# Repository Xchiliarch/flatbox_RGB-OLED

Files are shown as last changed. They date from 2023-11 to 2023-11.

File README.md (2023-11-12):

# Flatbox_RGB-OLED—A remix of Flatbox_rev5

- [What's this?](#whats-this)
- [What's new?](#whats-new)
- [What you need?](#what-you-need)

## What's this?

An adaption from [flatbox rev_5](https://github.com/Xchiliarch/flatbox_RGB-OLED/tree/master/hardware-rev5) , added RGB, OLED support and a new button.

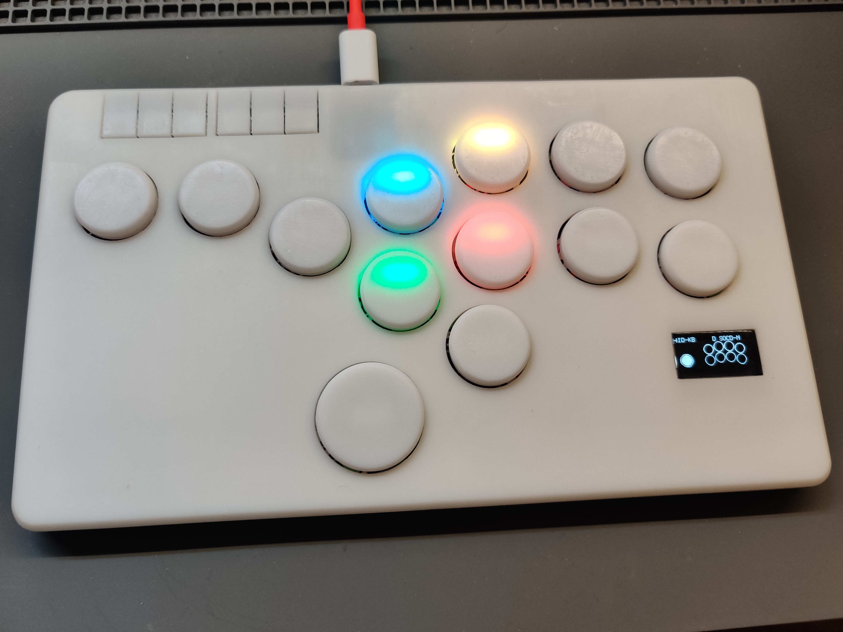
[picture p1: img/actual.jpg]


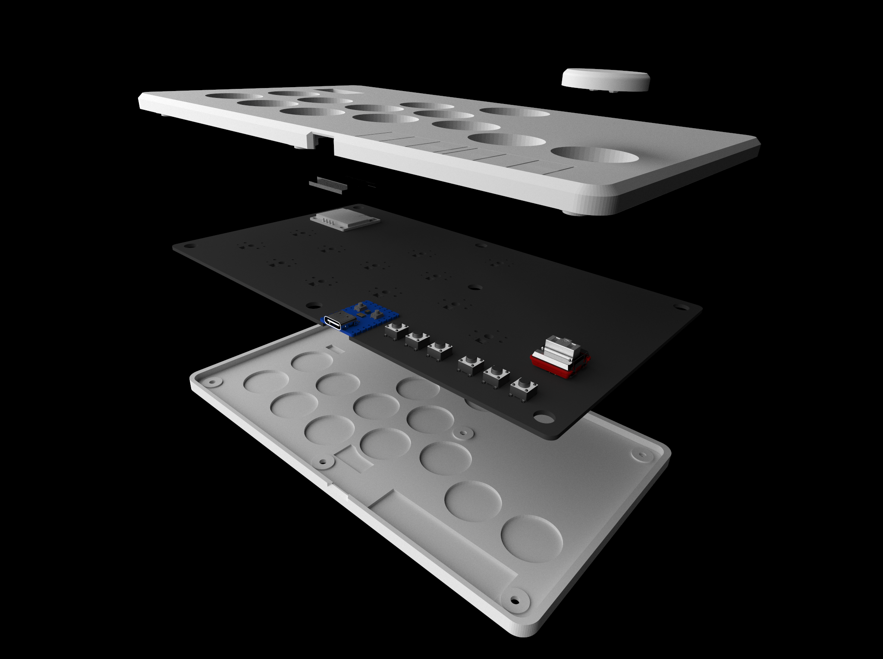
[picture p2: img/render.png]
render


## What's new?
- added RGB&OLED support
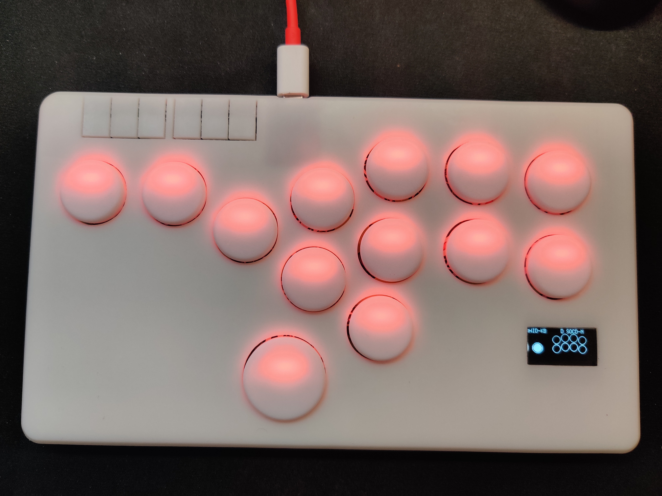
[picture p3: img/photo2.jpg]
actual2

- a new button

- buttons are at same level with the case when pressed down

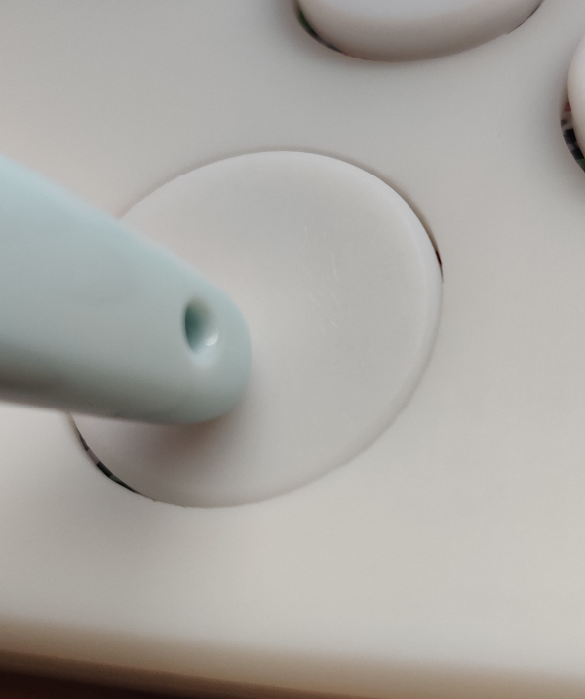
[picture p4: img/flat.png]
flat
  

## What you need?

| Parts | Name | Pcs  | Price |
| :---: | :--: | :---: | :---: |
|  | Waveshare RP2040-ZERO |  1 | ￥19 |
| choc | Kailh Choc V1 Switch | 13 | ￥3.2 ×13 |
| led | WS2812B 3528LED | 13 | ￥0.4 ×13 |
| insert | M3×5×4.2 Heat Set Insert | 7 | ￥0.09×7 |
| screw | M3×6 Flat-head Screw |  7 | ￥0.02×7  |
| OLED | SSD1306 0.96" OLED Display |  1 | ￥8 |
| c | 005 100NF capacitor | 13 | ￥0.03×13 |
| tact | 6mm×6mm×5mm tact switch | 6 | ￥0.12×6 |
| PCB | PCB | 1 | ￥110 for 5Pcs |
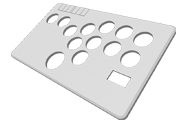
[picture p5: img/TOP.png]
TOP
|  | TOP case | 1 | ￥45* |
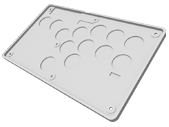
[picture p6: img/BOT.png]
BOT
|  | BOT case | 1 | ￥34* |
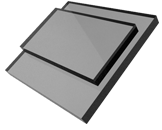
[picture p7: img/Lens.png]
LENS
|  | LENS(Transparent) | 1 | ￥12** |
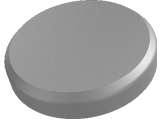
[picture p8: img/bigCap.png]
|  | big Cap | 1 | ￥2 |
| Bigcap | Small cap | 12 | ￥2×12 |

### Additional Info

All 3D printed case are from  JLC's 3D printing service (Sanweihou) and PCB order from JLC.

*: using  9000R, will be cheaper with X Resin.

**: using 8001+ Surface Finish: Oil Spraying. will be cheaper to sand it yourself.

## Credits

This project is made possible with the help of [GP2040-CE](https://github.com/OpenStickCommunity/GP2040-CE) by OpenStickCommunity and [Flatbox](https://github.com/jfedor2/flatbox) by jfedor2.

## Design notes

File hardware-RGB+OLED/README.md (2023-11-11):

## How to build

To make one you will need:

- 3D printed case TOP, BOT and LENS(transparent)
- PCB **thickness 1.6mm**
- 1x Waveshare RP2040-Zero
- 13x Kailh low profile (**choc v1**) switches
- 3D printed buttoncaps : **12x ButtoncapSmall** and **1x ButtoncapBig**
- 7x Heat-Set Inserts M3x5x4.2
- 7x M3x6 flat-end screws
- 6x 6x6x5  tact switches
- 13x WS2812B LED(3528)
- 13x 0805 100NF capacitor
- 1x SSD106 0.96" OLED Display (PIN SEQUENCE **MUST BE GND VSS SCL SDA**)

### NOTICE

- The three control buttons on the right (Fn,R3,L3)needed to be soldered with fly wires onto the back of the RP2040-ZERO. You can ignore the three buttons and still work well with only HOME SELECT and START, but it is better to solder the buttons on to the PCB in order to protect the vulnerable buttoncap on the top case.

- You need to cut off OLED pins that stretch out after being soldered on to the PCB to make it fit into the case. You may want to sand the pins as well.

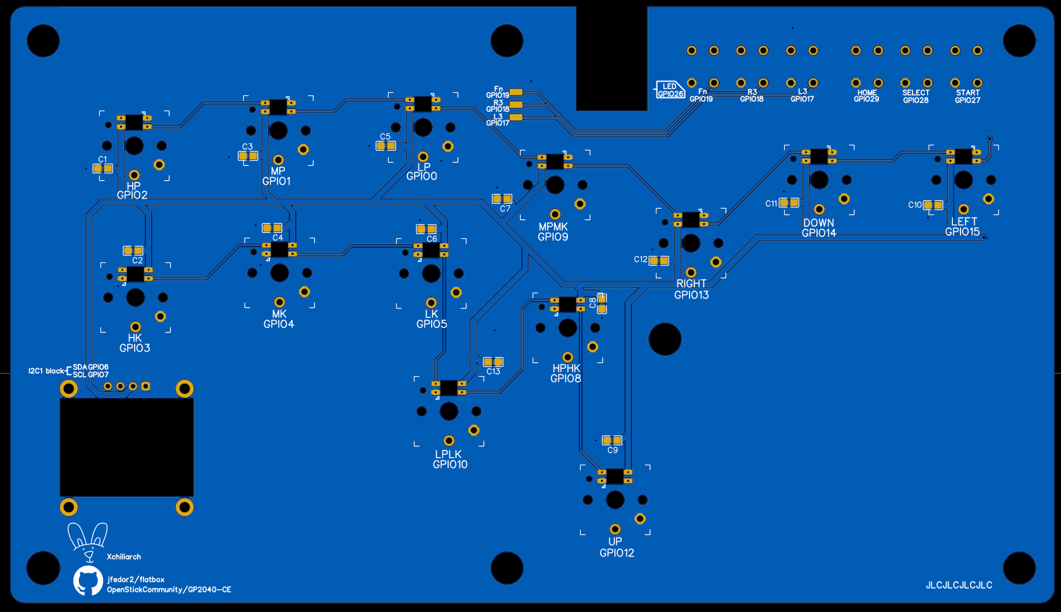
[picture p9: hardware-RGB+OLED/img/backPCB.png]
backPCB
 

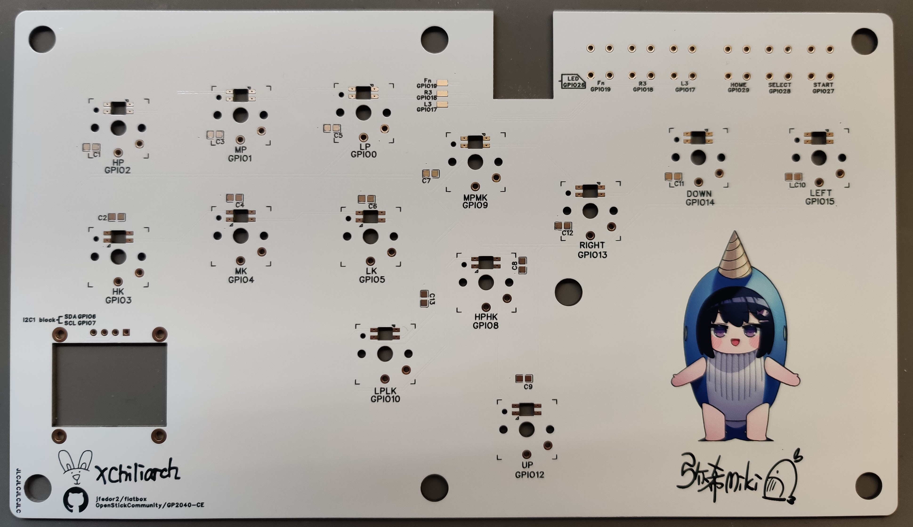
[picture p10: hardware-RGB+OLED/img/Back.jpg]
Back


PCB design licensed under [CC BY-SA 4.0](https://creativecommons.org/licenses/by-sa/4.0/).

PCB designed with JLC EDA.

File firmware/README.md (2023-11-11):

## How to use

- flash flash_nuke.uf2 to device to ensure a clean environment for installation
- flash GP2040-CE_0.7.5_WaveshareZero.uf2 and wait for auto disconnect and reconnection
- disconnect the device and hold the second last button on the upper row and connect to computer

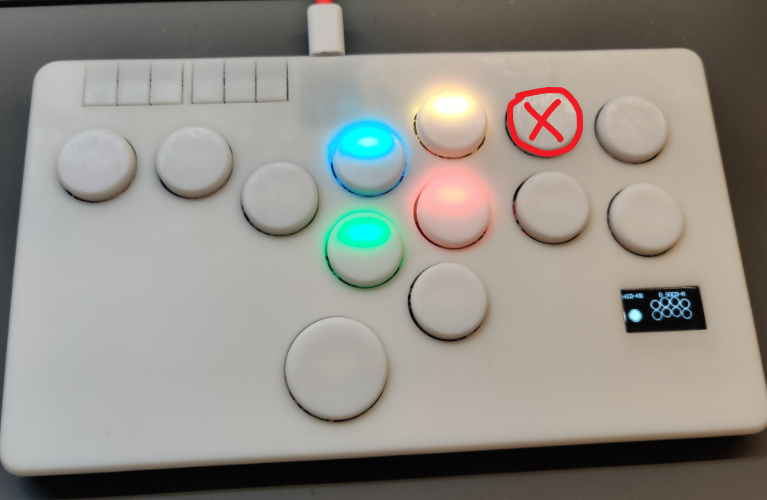
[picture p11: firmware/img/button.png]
button


- go to Data Backup and Restoration menu and load config.gp2040

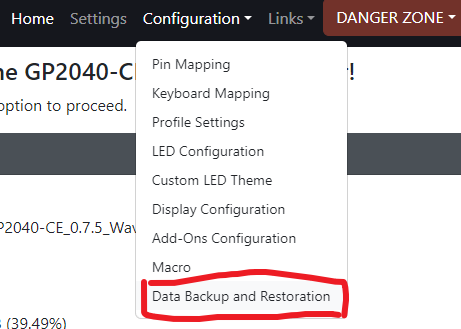
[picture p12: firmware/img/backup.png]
backup
  

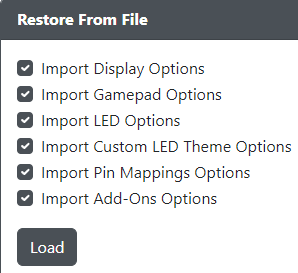
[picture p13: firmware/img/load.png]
load
  

- done!

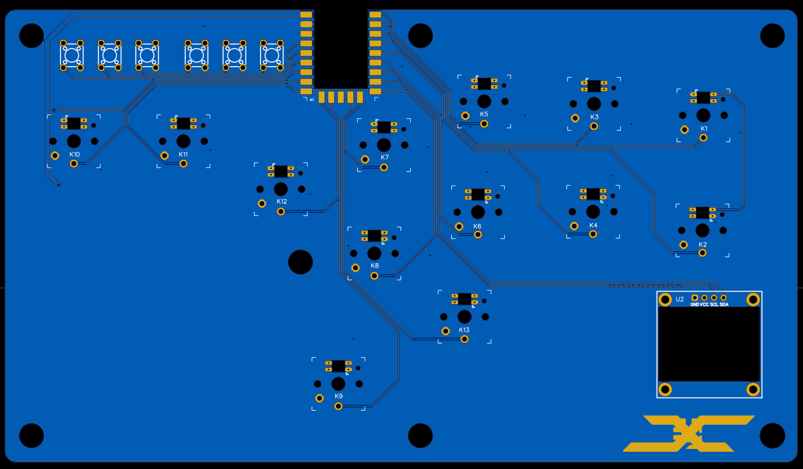
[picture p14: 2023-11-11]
hardware-RGB+OLED/img/frontPCB.png

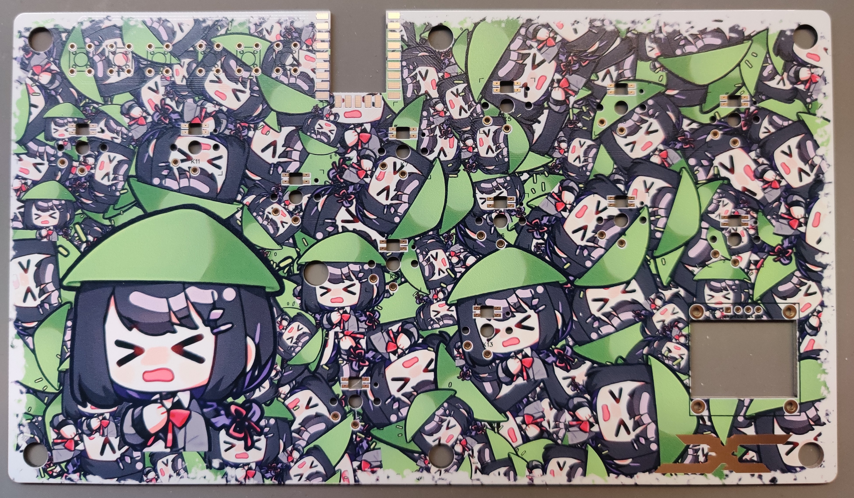
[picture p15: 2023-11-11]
hardware-RGB+OLED/img/Front.jpg

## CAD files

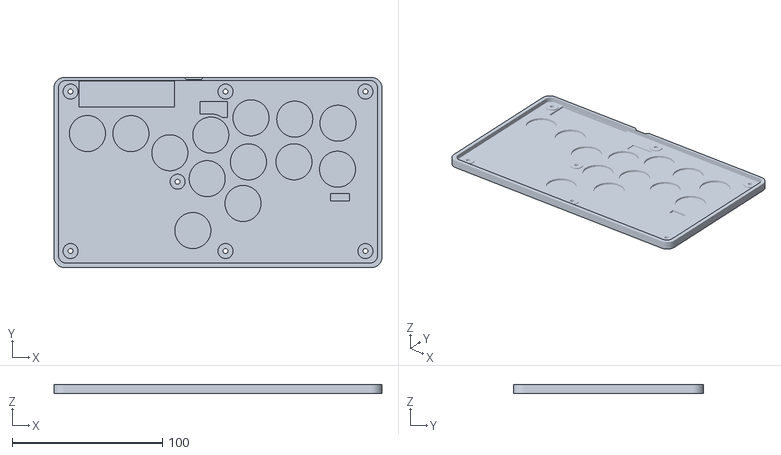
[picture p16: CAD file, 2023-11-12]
hardware-RGB+OLED/3dPrintedStuff/BOT.stl
218.0 x 126.4 x 6.20

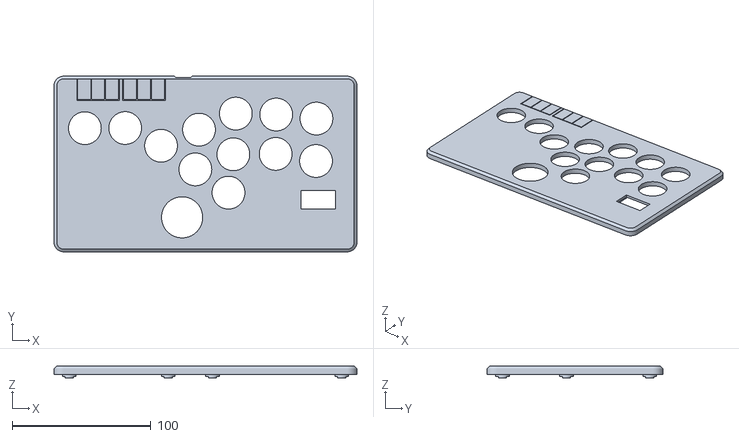
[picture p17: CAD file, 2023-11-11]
hardware-RGB+OLED/3dPrintedStuff/TOP.stl
218.0 x 126.4 x 8.70

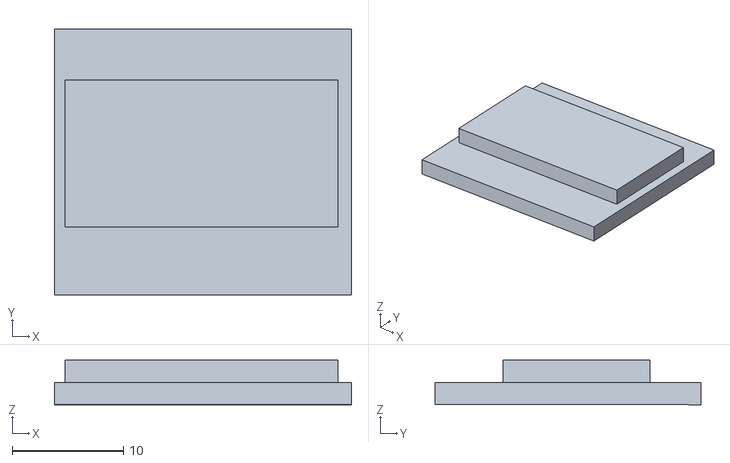
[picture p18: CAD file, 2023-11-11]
hardware-RGB+OLED/3dPrintedStuff/LENS.stl
26.7 x 23.9 x 4.00

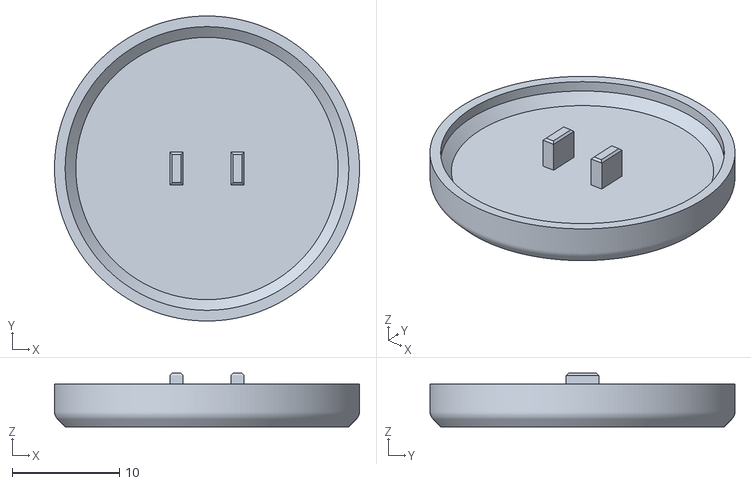
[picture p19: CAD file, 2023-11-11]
hardware-RGB+OLED/3dPrintedStuff/ButtoncapBig.stl
28.5 x 28.5 x 5.00

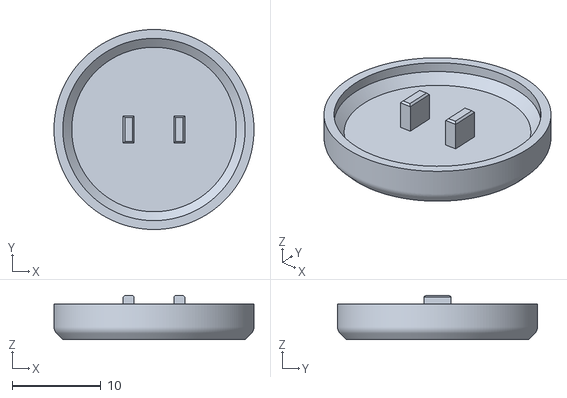
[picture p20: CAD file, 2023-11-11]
hardware-RGB+OLED/3dPrintedStuff/ButtoncapSmall.stl
22.5 x 22.5 x 5.00

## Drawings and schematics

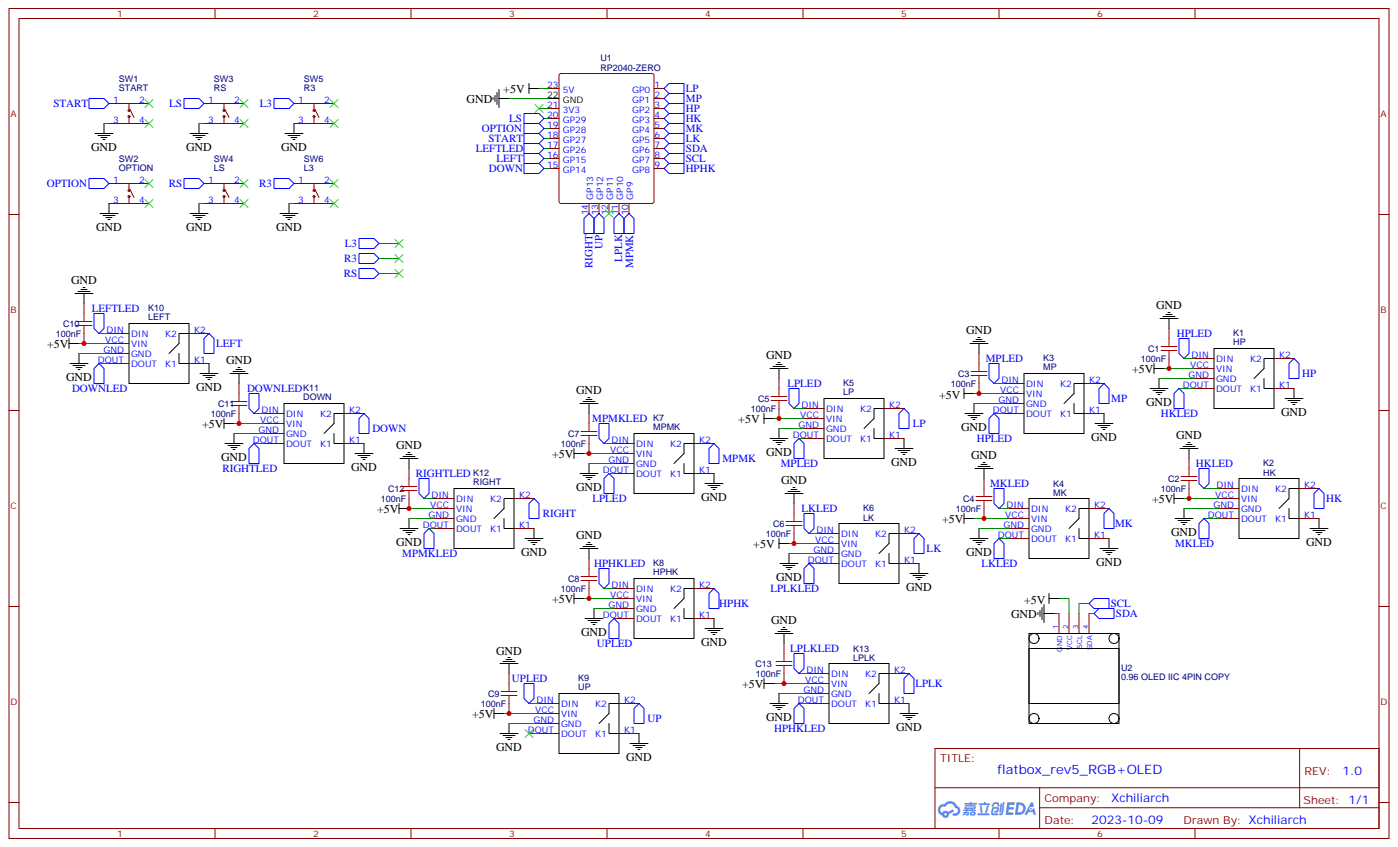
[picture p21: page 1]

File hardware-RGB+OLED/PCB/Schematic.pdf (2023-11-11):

# GP14 15 GP15 16 GP26 17 GP27 18 GP28 19 GP29 20 3V3 21 GND 22 5V 23
